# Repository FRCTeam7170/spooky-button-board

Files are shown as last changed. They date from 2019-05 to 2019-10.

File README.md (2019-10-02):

# spooky-button-board
Java code for controlling custom IO expander Raspberry Pi HAT for a button
board.

The IO expanders used are MCP23S17's, which have 16 GPIOs with an SPI
interface. The library used to interface with the chips can be found
[here](https://github.com/Ro5bert/MCP23S17) (JAR releases of it are included
in `lib`.)

The KiCAD schematic and PCB layout can be found in the [kicad folder](kicad).

## Building
To build, clone this repository and run

    ./gradlew shadowJar
    
(Note that, since this was copied from Windows, `gradlew` might not be
executable by default. To make it executable, run `chmod 750 gradlew`.)

This will produce an executable JAR in `build/libs`.

## Running
To execute the JAR produced under Building, simply run

    java -jar /path/to/jar
    
which might need root privileges to access the SPI hardware (prepend with
`sudo`).

## Configuration

### Enabling SPI Interface
The Raspberry Pi's SPI interface must be enabled in order to communicate with
the SPI IO expanders; by default, it is disabled. To enable it run

    raspi-config
    
(needs root privileges; prepend with `sudo` if not root user) and navigate
with the up/down arrow keys to "5 Interfacing Options", then "P4 SPI", and
enable it. Then, use the left/right arrow keys to select "Finish".

### Executing JAR on Boot
It is probably desirable to have to JAR execute when the Raspberry Pi boots.
To do so, we can execute the JAR in `/etc/rc.local`, which is executed on
startup. Edit `rc.local` (`sudo nano /etc/rc.local`) and insert the following
line before the `exit` statement:

    java -jar /path/to/jar > /var/log/sbb.log 2>&1 &
    
(Note `sudo` is not necessary here as `rc.local` is executed as the root
user.)

The "`&`" at the end of the line makes the command run in the background and
is recommended as, without it, the rest of the initialization process will be
blocked as it waits for Java to terminate. (You also will not be able to
manually terminate it via Ctrl-C because it is not started from a shell you
are logged into!) The "`> /var/log/sbb.log`" and "`2>&1`" parts are optional;
they redirect standard output to `/var/log/sbb.log` ("sbb" for
"spooky-button-board") and standard error to standard output (and,
consequently, `/var/log/sbb.log`).

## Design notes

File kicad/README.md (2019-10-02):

# KiCAD Files for spooky-button-board
The KiCAD schematic and PCB files and other related files can be found here.

The PCB layout was designed with the intention to have it manufactured by
[JLCPCB](https://jlcpcb.com/) and therefore uses constraints (trace width, via
diameter, etc.) within
[their capabilities](https://jlcpcb.com/capabilities/Capabilities).

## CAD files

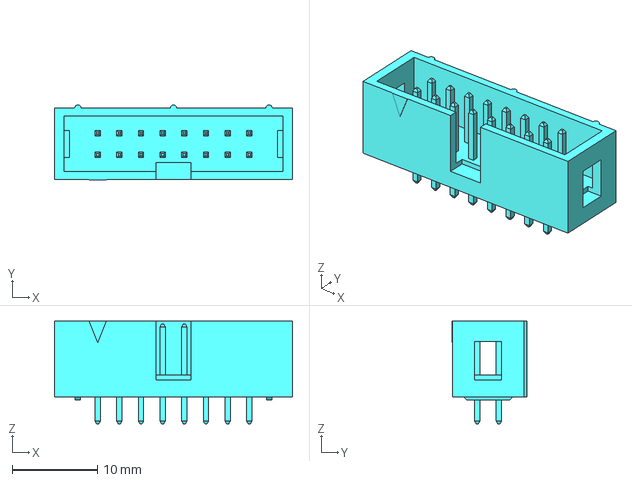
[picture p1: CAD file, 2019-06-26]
kicad/30316-6002.stp
27.9 x 8.81 x 12.1 mm

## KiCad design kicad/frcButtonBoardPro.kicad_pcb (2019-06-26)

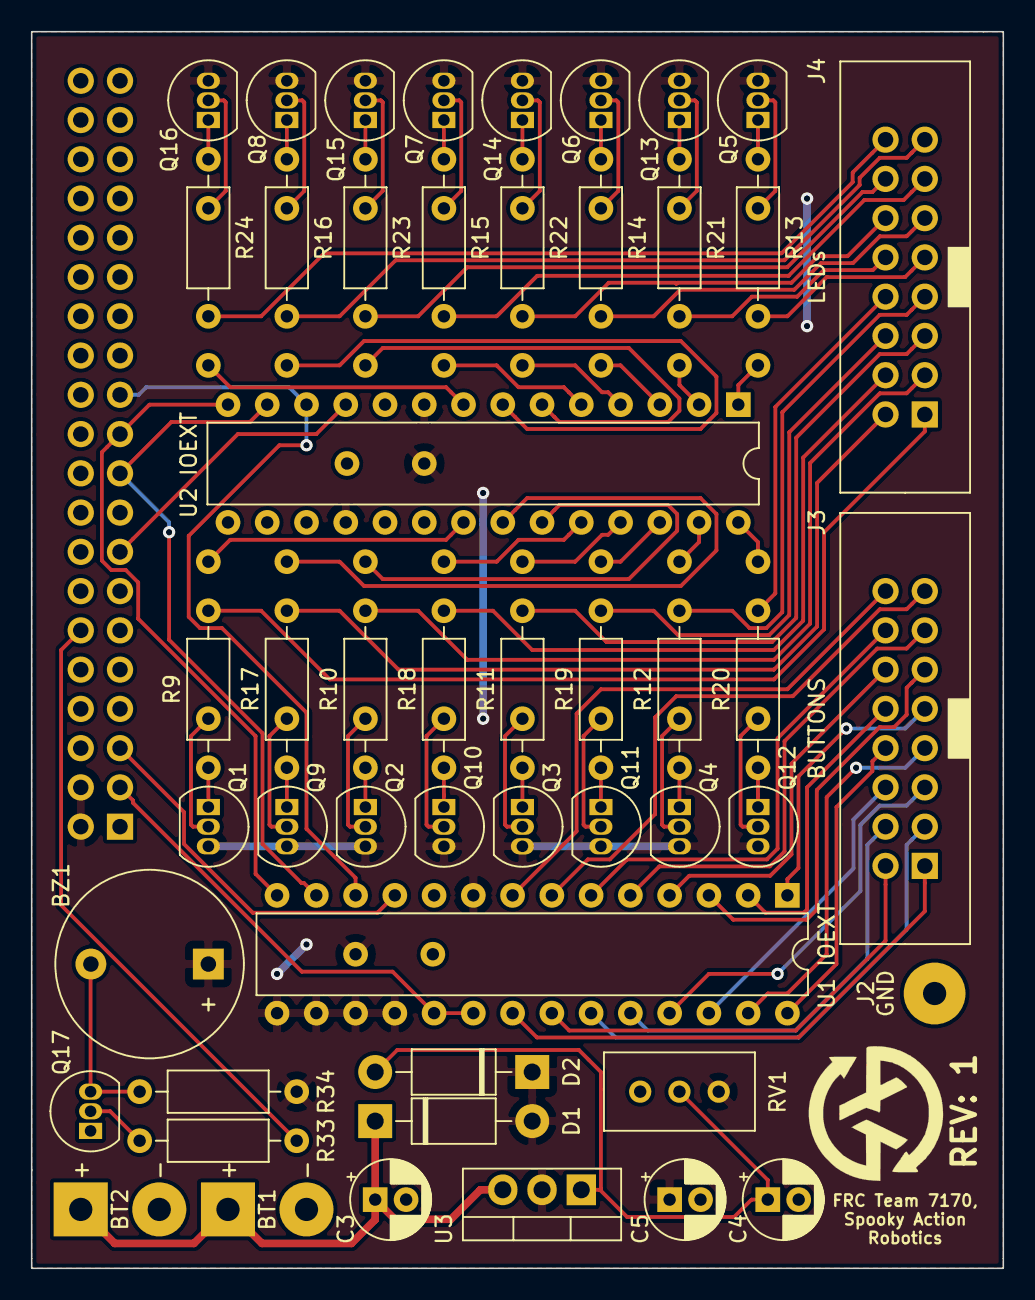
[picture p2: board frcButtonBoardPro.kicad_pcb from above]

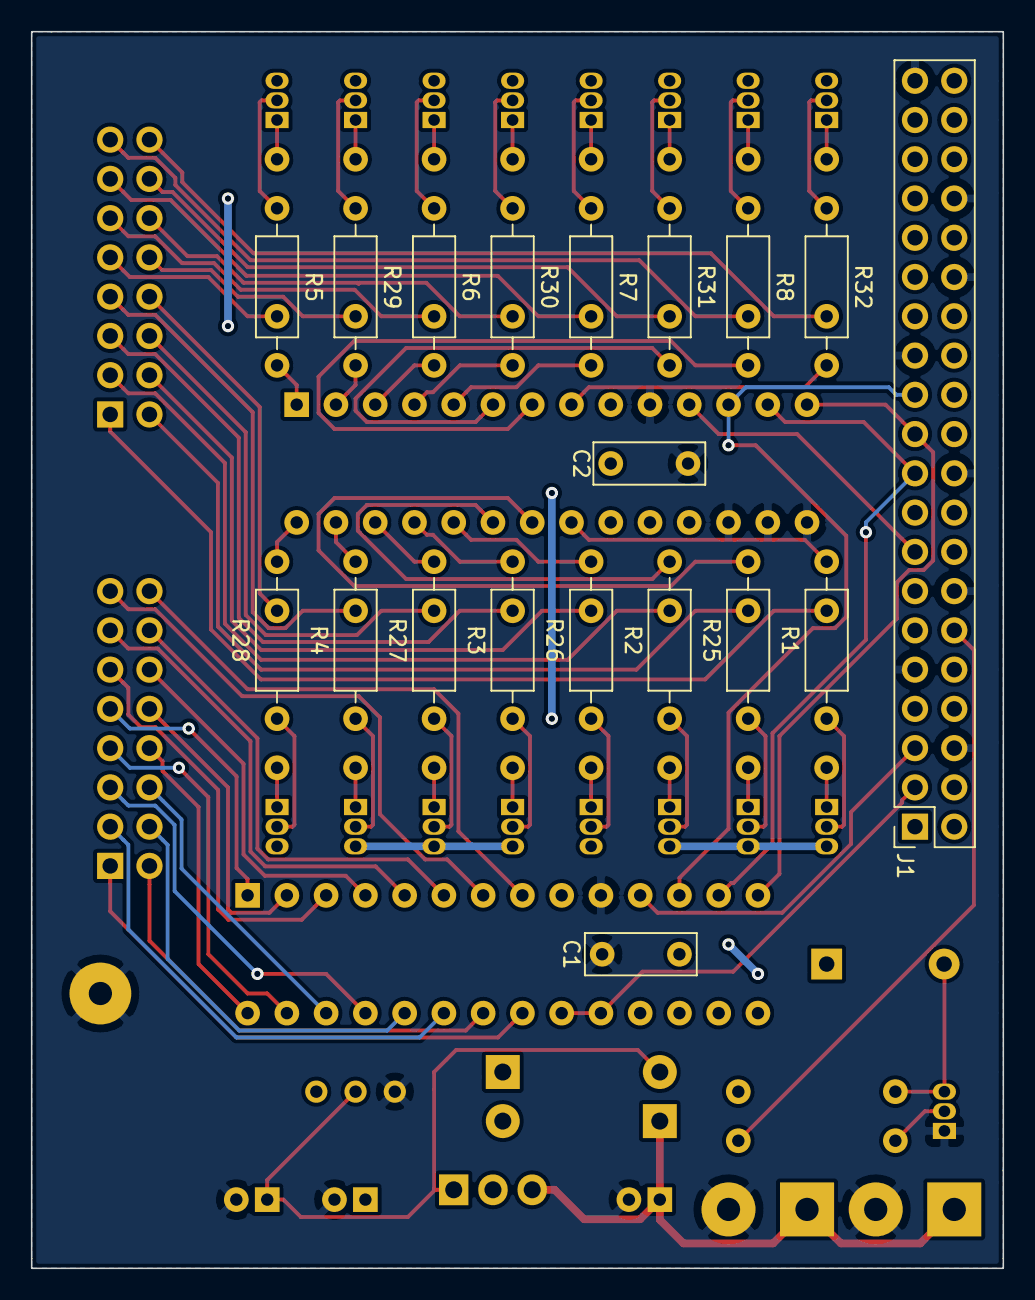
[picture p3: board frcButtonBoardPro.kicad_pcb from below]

Board: 2 copper layers, 62.9 x 80.0 mm, 69 parts (19 on the bottom side), 93 nets.

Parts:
BT1, BT2: Battery; SolderWirePad_1x02_P5.08mm_Drill1.5mm
BZ1: Buzzer; Buzzer_12x9.5RM7.6
C1, C2: 100n; C_Rect_L7.0mm_W2.5mm_P5.00mm
C3, C4, C5: 10u; CP_Radial_D5.0mm_P2.00mm
D1, D2: 1N4002; D_DO-41_SOD81_P10.16mm_Horizontal
J1: Raspberry_Pi_2_3; PinSocket_2x20_P2.54mm_Vertical
J2: Conn_01x01; SolderWirePad_1x01_Drill1.5mm
J3, J4: Conn_02x08_Odd_Even; 16PIN_RIBBON_CONN
Q1, Q2, Q3, Q4, Q5, Q6, Q7, Q8, Q9, Q10, Q11, Q12, Q13, Q14, Q15, Q16, Q17: 2N3904; TO-92_Inline
R1, R2, R3, R4, R5, R6, R7, R8, R25, R26, R27, R28, R29, R30, R31, R32: 10K; R_Axial_DIN0207_L6.3mm_D2.5mm_P10.16mm_Horizontal
R9, R10, R11, R12, R13, R14, R15, R16, R17, R18, R19, R20, R21, R22, R23, R24: 100R; R_Axial_DIN0207_L6.3mm_D2.5mm_P10.16mm_Horizontal
R33, R34: 1K; R_Axial_DIN0207_L6.3mm_D2.5mm_P10.16mm_Horizontal
RV1: R_POT_TRIM_US; Potentiometer_Bourns_3296W_Vertical
U1, U2: MCP23S17_SP; DIP-28_W7.62mm
U3: LM317_3PinPackage; TO-220-3_Vertical

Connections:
+5V: BZ1.1, C1.1, C2.1, C5.1, D1.2, D2.1, J1.2, J1.4, Q1.3, Q2.3, Q3.3, Q4.3, Q5.3, Q6.3, Q7.3, Q8.3, Q9.3, Q10.3, Q11.3, Q12.3, Q13.3, Q14.3, Q15.3, Q16.3, R34.1, RV1.3, U1.9, U1.15, U1.16, U1.17, U1.18, U2.9, U2.18, U3.2
/INT: J1.3, U1.19, U1.20
/MISO: J1.21, U1.14, U2.14
/MOSI: J1.19, U1.13, U2.13
/SCLK: J1.23, U1.12, U2.12
/buttons/BUTTON1: J3.1, U1.21
/buttons/BUTTON2: J3.2, U1.22
/buttons/BUTTON3: J3.3, U1.23
/buttons/BUTTON4: J3.4, U1.24
/buttons/BUTTON5: J3.5, U1.25
/buttons/BUTTON6: J3.6, U1.26
/buttons/BUTTON7: J3.7, U1.27
/buttons/BUTTON8: J3.8, U1.28
/buttons/BUTTON9: J3.9, U1.1
/buttons/BUTTON10: J3.10, U1.2
/buttons/BUTTON11: J3.11, U1.3
/buttons/BUTTON12: J3.12, U1.4
/buttons/BUTTON13: J3.13, U1.5
/buttons/BUTTON14: J3.14, U1.6
/buttons/BUTTON15: J3.15, U1.7
/buttons/BUTTON16: J3.16, U1.8
/buzzer/BUZZER_PWM: J1.12, R33.2
/leds/LED1: R1.2, U2.21
/leds/LED2: R25.2, U2.22
/leds/LED3: R2.2, U2.23
/leds/LED4: R26.2, U2.24
/leds/LED5: R3.2, U2.25
/leds/LED6: R27.2, U2.26
/leds/LED7: R4.2, U2.27
/leds/LED8: R28.2, U2.28
/leds/LED9: R5.2, U2.1
/leds/LED10: R29.2, U2.2
/leds/LED11: R6.2, U2.3
/leds/LED12: R30.2, U2.4
/leds/LED13: R7.2, U2.5
/leds/LED14: R31.2, U2.6
/leds/LED15: R8.2, U2.7
/leds/LED16: R32.2, U2.8
/~CS_Buttons: J1.5, U1.11
/~CS_LEDs: J1.15, U2.11
GND: BT1.2, BT2.2, C1.2, C2.2, C3.2, C4.2, C5.2, J1.6, J1.9, J1.14, J1.20, J1.25, J1.30, J1.34, J1.39, J2.1, Q17.1, RV1.1, U1.10, U2.10, U2.15, U2.16, U2.17
unnamed: BT1.1, BT2.1, C3.1, D1.1, U3.3
unnamed: BZ1.2, Q17.3, R34.2
unnamed: C4.1, D2.2, RV1.2, U3.1
unnamed: J4.1, R9.2
unnamed: J4.2, R17.2
unnamed: J4.3, R10.2
unnamed: J4.4, R18.2
unnamed: J4.5, R11.2
unnamed: J4.6, R19.2
unnamed: J4.7, R12.2
unnamed: J4.8, R20.2
unnamed: J4.9, R13.2
unnamed: J4.10, R21.2
unnamed: J4.11, R14.2
unnamed: J4.12, R22.2
unnamed: J4.13, R15.2
unnamed: J4.14, R23.2
unnamed: J4.15, R16.2
unnamed: J4.16, R24.2
unnamed: Q1.1, R9.1
unnamed: Q1.2, R1.1
unnamed: Q2.1, R10.1
unnamed: Q2.2, R2.1
unnamed: Q3.1, R11.1
unnamed: Q3.2, R3.1
unnamed: Q4.1, R12.1
unnamed: Q4.2, R4.1
unnamed: Q5.1, R13.1
unnamed: Q5.2, R5.1
unnamed: Q6.1, R14.1
unnamed: Q6.2, R6.1
unnamed: Q7.1, R15.1
unnamed: Q7.2, R7.1
unnamed: Q8.1, R16.1
unnamed: Q8.2, R8.1
unnamed: Q9.1, R17.1
unnamed: Q9.2, R25.1
unnamed: Q10.1, R18.1
unnamed: Q10.2, R26.1
unnamed: Q11.1, R19.1
unnamed: Q11.2, R27.1
unnamed: Q12.1, R20.1
unnamed: Q12.2, R28.1
unnamed: Q13.1, R21.1
unnamed: Q13.2, R29.1
unnamed: Q14.1, R22.1
unnamed: Q14.2, R30.1
unnamed: Q15.1, R23.1
unnamed: Q15.2, R31.1
unnamed: Q16.1, R24.1
unnamed: Q16.2, R32.1
unnamed: Q17.2, R33.1

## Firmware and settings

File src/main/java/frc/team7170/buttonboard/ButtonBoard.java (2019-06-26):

package frc.team7170.buttonboard;

import com.pi4j.io.gpio.*;
import com.pi4j.io.spi.SpiChannel;
import com.rrr.mcp23s17.MCP23S17;
import edu.wpi.first.networktables.*;

import java.io.IOException;
import java.util.*;
import java.util.function.BiConsumer;

// TODO: Documentation
// TODO: add instructions to connect to robot radio in README
public final class ButtonBoard {

    private static final int TEAM_NUMBER = 7170;

    private static final Map<MCP23S17.Pin, CommandService> BUTTON_PIN_COMMAND_SERVICE_MAP = new HashMap<>();

    static {
        // Initialize IO Expanders.
        GpioController gpioController = GpioFactory.getInstance();
        GpioPinDigitalOutput invCSLEDs = gpioController.provisionDigitalOutputPin(RaspiPin.GPIO_03);
        GpioPinDigitalOutput invCSButtons = gpioController.provisionDigitalOutputPin(RaspiPin.GPIO_09);
        GpioPinDigitalInput interrupt = gpioController.provisionDigitalInputPin(RaspiPin.GPIO_08);
        try {
            leds = MCP23S17.newWithoutInterrupts(SpiChannel.CS0, invCSLEDs);
            buttons = MCP23S17.newWithTiedInterrupts(SpiChannel.CS0, invCSButtons, interrupt);
        } catch (IOException e) {
            System.err.println("failed IO expander initialization");
            throw new RuntimeException(e);
        }

        // Populate BUTTON_PIN_COMMAND_SERVICE_MAP.
        BiConsumer<MCP23S17.Pin, Boolean> pinSetter = ButtonBoard::setLEDUnchecked;
        BUTTON_PIN_COMMAND_SERVICE_MAP.put(MCP23S17.Pin.PIN4, new CommandService(
                new DeterministicCommandResolver(Command.ELEVATOR_LEVEL_1),
                new BlinkingLEDDisplayHandler(pinSetter))
        );
        BUTTON_PIN_COMMAND_SERVICE_MAP.put(MCP23S17.Pin.PIN5, new CommandService(
                new DeterministicCommandResolver(Command.ELEVATOR_LEVEL_2),
                new BlinkingLEDDisplayHandler(pinSetter))
        );
        BUTTON_PIN_COMMAND_SERVICE_MAP.put(MCP23S17.Pin.PIN6, new CommandService(
                new DeterministicCommandResolver(Command.ELEVATOR_LEVEL_3),
                new BlinkingLEDDisplayHandler(pinSetter))
        );
        BUTTON_PIN_COMMAND_SERVICE_MAP.put(MCP23S17.Pin.PIN9, new CommandService(
                new DeterministicCommandResolver(Command.FRONT_ARMS_VERTICAL),
                new BlinkingLEDDisplayHandler(pinSetter))
        );
        BUTTON_PIN_COMMAND_SERVICE_MAP.put(MCP23S17.Pin.PIN8, new CommandService(
                new DeterministicCommandResolver(Command.FRONT_ARMS_HORIZONTAL),
                new BlinkingLEDDisplayHandler(pinSetter))
        );
        BUTTON_PIN_COMMAND_SERVICE_MAP.put(MCP23S17.Pin.PIN1, new CommandService(
                new DeterministicCommandResolver(Command.EJECT),
                new BlinkingLEDDisplayHandler(pinSetter))
        );
        BUTTON_PIN_COMMAND_SERVICE_MAP.put(MCP23S17.Pin.PIN0, new CommandService(
                new DeterministicCommandResolver(Command.PIN_TOGGLE),
                new BlinkingLEDDisplayHandler(pinSetter))
        );
        BUTTON_PIN_COMMAND_SERVICE_MAP.put(MCP23S17.Pin.PIN14, new CommandService(
                new DeterministicCommandResolver(Command.LEFT_DRIVE_WHEELS_FORWARD),
                new FollowingLEDDisplayHandler(pinSetter))
        );
        BUTTON_PIN_COMMAND_SERVICE_MAP.put(MCP23S17.Pin.PIN15, new CommandService(
                new DeterministicCommandResolver(Command.LEFT_DRIVE_WHEELS_REVERSE),
                new FollowingLEDDisplayHandler(pinSetter))
        );
        BUTTON_PIN_COMMAND_SERVICE_MAP.put(MCP23S17.Pin.PIN12, new CommandService(
                new DeterministicCommandResolver(Command.RIGHT_DRIVE_WHEELS_FORWARD),
                new FollowingLEDDisplayHandler(pinSetter))
        );
        BUTTON_PIN_COMMAND_SERVICE_MAP.put(MCP23S17.Pin.PIN13, new CommandService(
                new DeterministicCommandResolver(Command.RIGHT_DRIVE_WHEELS_REVERSE),
                new FollowingLEDDisplayHandler(pinSetter))
        );
        BUTTON_PIN_COMMAND_SERVICE_MAP.put(MCP23S17.Pin.PIN11, new CommandService(
                new DeterministicCommandResolver(Command.LINEAR_ACTUATOR_RETRACT),
                new FollowingLEDDisplayHandler(pinSetter))
        );
        BUTTON_PIN_COMMAND_SERVICE_MAP.put(MCP23S17.Pin.PIN10, new CommandService(
                new DeterministicCommandResolver(Command.LINEAR_ACTUATOR_EXTEND),
                new FollowingLEDDisplayHandler(pinSetter))
        );
        BUTTON_PIN_COMMAND_SERVICE_MAP.put(MCP23S17.Pin.PIN7, new CommandService(
                new DeterministicCommandResolver(Command.SPIN_CLIMB_DRIVE_WHEELS),
                new FollowingLEDDisplayHandler(pinSetter))
        );
        BUTTON_PIN_COMMAND_SERVICE_MAP.put(MCP23S17.Pin.PIN2, new CommandService(
                new DeterministicCommandResolver(Command.SHUFFLE_LATERAL_SLIDE),
                new BlinkingLEDDisplayHandler(pinSetter))
        );
        BUTTON_PIN_COMMAND_SERVICE_MAP.put(MCP23S17.Pin.PIN3, new CommandService(
                new RandomCommandResolver(
                        Command.ELEVATOR_LEVEL_1,
                        Command.ELEVATOR_LEVEL_2,
                        Command.ELEVATOR_LEVEL_3,
                        Command.FRONT_ARMS_VERTICAL,
                        Command.FRONT_ARMS_HORIZONTAL,
                        Command.EJECT,
                        Command.PIN_TOGGLE,
                        Command.SHUFFLE_LATERAL_SLIDE
                ),
                new RandomDisplayHandler(pinSetter, gpioController.provisionPwmOutputPin(RaspiPin.GPIO_01)))
        );
    }

    private static MCP23S17 leds;
    private static MCP23S17 buttons;
    private static NetworkTableEntry pressedEntry;
    private static NetworkTableEntry releasedEntry;
    private static final List<String> pressedCache = new ArrayList<>();
    private static final List<String> releasedCache = new ArrayList<>();

    // Timings on busy loop pin-toggling:
    // period: ~1.2 us
    // rise time: <15 ns
    public static void main(String... args) {
        // Configure IO Expanders.
        try {
            // Configure LEDs IO Expander.
            for (Iterator<MCP23S17.PinView> iter = leds.getPinViewIterator(); iter.hasNext();) {
                MCP23S17.PinView pinView = iter.next();
                pinView.setAsOutput();
                pinView.set(true);
            }
            leds.writeIODIRA();
            leds.writeIODIRB();
            leds.writeOLATA();
            leds.writeOLATB();

            // Configure buttons IO Expander.
            for (Iterator<MCP23S17.PinView> iter = buttons.getPinViewIterator(); iter.hasNext();) {
                MCP23S17.PinView pinView = iter.next();
                pinView.enableInterrupt();
//                pinView.setDefaultComparisonValue(true);
//                pinView.toInterruptComparisonMode();
                pinView.enablePullUp();
            }
            buttons.writeGPPUA();
            buttons.writeGPPUB();
//            buttons.writeDEFVALA();
//            buttons.writeDEFVALB();
//            buttons.writeINTCONA();
//            buttons.writeINTCONB();
            buttons.writeGPINTENA();
            buttons.writeGPINTENB();
        } catch (IOException e) {
            System.err.println("failed IO expander configuration");
            throw new RuntimeException(e);
        }

        // Initialize network tables.
        {
            NetworkTableInstance instance = NetworkTableInstance.getDefault();
            System.out.println("Waiting for robot connection...");
            instance.startClientTeam(TEAM_NUMBER);
            try {
                // Block until NT connects.
                while (!instance.isConnected()) {
                    Thread.sleep(100);
                }
            } catch (InterruptedException e) {
                // Main thread should never be interrupted.
                throw new AssertionError(e);
            }
            System.out.println("Connected!");
            pulseAllLEDs(3);  // For visual indication that NT connected.
            pressedEntry = instance.getEntry("buttonBoardPressed");
            releasedEntry = instance.getEntry("buttonBoardReleased");
        }

        pressedEntry.setStringArray(new String[0]);  // Set type.
        releasedEntry.setStringArray(new String[0]);  // Set type.
        pressedEntry.addListener(ButtonBoard::onPressedEntryCleared, EntryListenerFlags.kUpdate);
        releasedEntry.addListener(ButtonBoard::onReleasedEntryCleared, EntryListenerFlags.kUpdate);
        buttons.addGlobalListener(ButtonBoard::onButtonUpdate);
        System.out.println("Awaiting button presses...");

        // For testing.
//        try (Scanner scanner = new Scanner(System.in)) {
//            Random random = new Random();
//            MCP23S17.Pin pin = null;
//            while (true) {
//                scanner.nextLine();
//                int pinNumber = random.nextInt(16);
//                if (pin != null) {
//                    setLEDUnchecked(pin, false);
//                }
//                pin = MCP23S17.Pin.fromPinNumber(pinNumber);
//                setLEDUnchecked(pin, true);
//                System.out.println(pinNumber);
//                if (false) {
//                    break;
//                }
//            }
//        }

        try {
            // Nothing else to do in main thread; we're just waiting for interrupts now.
            Thread.currentThread().join();
        } catch (InterruptedException e) {
            // Main thread should never be interrupted.
            throw new AssertionError(e);
        }
    }

    private static void onPressedEntryCleared(EntryNotification notification) {
        if (notification.value.getStringArray().length != 0) {
            throw new RuntimeException("stream protocol violated: entry updated to non-empty array");
        }
        flushPressed();
    }

    private static void onReleasedEntryCleared(EntryNotification notification) {
        if (notification.value.getStringArray().length != 0) {
            throw new RuntimeException("stream protocol violated: entry updated to non-empty array");
        }
        flushReleased();
    }

    private static void flushPressed() {
        if (!pressedCache.isEmpty()) {
            pressedEntry.setStringArray((String[]) pressedCache.toArray());
            pressedCache.clear();
        }
    }

    private static void flushReleased() {
        if (!releasedCache.isEmpty()) {
            releasedEntry.setStringArray((String[]) releasedCache.toArray());
            releasedCache.clear();
        }
    }

    private static void postPressedCommand(Command command) {
        pressedCache.add(command.name());
        if (pressedEntry.getValue().getStringArray().length == 0) {
            flushPressed();
        }
    }

    private static void postReleasedCommand(Command command) {
        releasedCache.add(command.name());
        if (releasedEntry.getValue().getStringArray().length == 0) {
            flushReleased();
        }
    }

    private static void onButtonUpdate(boolean state, MCP23S17.Pin pin) {
        CommandService commandService = BUTTON_PIN_COMMAND_SERVICE_MAP.get(pin);
        if (state) {
            System.out.println(String.format("Button %d released.", pin.getPinNumber()));
            postReleasedCommand(commandService.getForRelease());
        } else {
            System.out.println(String.format("Button %d pressed.", pin.getPinNumber()));
            postPressedCommand(commandService.getForPress());
        }
    }

    @SuppressWarnings("SynchronizeOnNonFinalField")
    private static void setLEDUnchecked(MCP23S17.Pin pin, boolean state) {
        try {
            // LEDs default to on, hence the negation here.
            leds.getPinView(pin).set(!state);
            // Register writes on MCP23S17 are not thread-safe--external synchronization required here.
            synchronized (leds) {
                if (pin.isPortA()) {
                    leds.writeOLATA();
                } else {
                    leds.writeOLATB();
                }
            }
        } catch (IOException e) {
            System.err.println("failed to set LED");
            throw new RuntimeException(e);
        }
    }

    private static void writeAllLEDsUnchecked(boolean state) {
        try {
            for (MCP23S17.Pin pin : MCP23S17.Pin.values()) {
                // LEDs default to on, hence the negation here.
                leds.getPinView(pin).set(!state);
            }
            leds.writeOLATA();
            leds.writeOLATB();
        } catch (IOException e) {
            System.err.println("failed to set LEDs");
            throw new RuntimeException(e);
        }
    }

    private static void pulseAllLEDs(int times) {
        for (int i = 0; i < times; ++i) {
            try{
                writeAllLEDsUnchecked(true);
                Thread.sleep(500);
                writeAllLEDsUnchecked(false);
                Thread.sleep(500);
            } catch (InterruptedException e) {
                // Main thread should never be interrupted.
                throw new AssertionError(e);
            }
        }
    }
}

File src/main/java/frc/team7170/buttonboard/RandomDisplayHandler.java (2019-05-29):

package frc.team7170.buttonboard;

import com.pi4j.io.gpio.GpioPinPwmOutput;
import com.rrr.mcp23s17.MCP23S17;

import java.util.Random;
import java.util.function.BiConsumer;

public class RandomDisplayHandler implements DisplayHandler {

    private static final int BUZZER_PWM_VALUE_RANDOM = 500;  // [0, 1023]
    private static final int NUM_RANDOM_JUMPS = 15;
    // Total period is 500 ms, buzzer on for half that, LED on for all of it.
    private static final int RANDOM_ON_TIME_MS = 250;
    private static final int RANDOM_OFF_TIME_MS = 250;
    private static final int BUZZER_PWM_VALUE_FINAL = 800;  // [0, 1023]
    private static final int NUM_FINAL_BLINKS = 3;
    private static final int FINAL_ON_TIME_MS = 250;
    private static final int FINAL_OFF_TIME_MS = 100;

    private final BiConsumer<MCP23S17.Pin, Boolean> ledSetter;
    private final GpioPinPwmOutput buzzer;
    private final Random random = new Random();

    public RandomDisplayHandler(BiConsumer<MCP23S17.Pin, Boolean> ledSetter, GpioPinPwmOutput buzzer) {
        this.ledSetter = ledSetter;
        this.buzzer = buzzer;
    }

    @Override
    public void buttonPressed(MCP23S17.Pin ledPin) {
        MCP23S17.Pin[] pins = MCP23S17.Pin.values();
        int last = 0;
        try {
            for (int i = 0; i < NUM_RANDOM_JUMPS; ++i) {
                // This never selects 0 as the first pin... not ideal.
                int randomPinNumber = last;
                while (randomPinNumber == last) {
                    randomPinNumber = random.nextInt(pins.length);
                }
                last = randomPinNumber;
                MCP23S17.Pin randomPin = pins[randomPinNumber];
                ledSetter.accept(randomPin, true);
                buzzer.setPwm(BUZZER_PWM_VALUE_RANDOM);
                Thread.sleep(RANDOM_ON_TIME_MS);
                buzzer.setPwm(0);
                Thread.sleep(RANDOM_OFF_TIME_MS);
                ledSetter.accept(randomPin, false);
            }
            for (int i = 0; i < NUM_FINAL_BLINKS; ++i) {
                ledSetter.accept(ledPin, true);
                buzzer.setPwm(BUZZER_PWM_VALUE_FINAL);
                Thread.sleep(FINAL_ON_TIME_MS);
                ledSetter.accept(ledPin, false);
                buzzer.setPwm(0);
                Thread.sleep(FINAL_OFF_TIME_MS);
            }
        } catch (InterruptedException e) {
            // GPIO event thread should never be interrupted (I think).
            throw new AssertionError(e);
        }
    }

    @Override
    public void buttonReleased(MCP23S17.Pin ledPin) {}
}

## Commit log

2019-05-28 Add stuff to handle LEDs switching on button presses.
2019-06-25 Add in pin numbers corresponding to physical connections. Remove (comment out) temporary code for testing.
2019-06-26 Minor README formatting. Remove TODOs from ButtonBoard.
2019-06-26 Add KiCad files with corresponding README.
    [30316-6002.stp, buttons.sch, buzzer.sch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]
2019-10-02 Update README: add reference to kicad folder
2019-10-02 Update kicad/README: capitalize CAD in KiCAD
